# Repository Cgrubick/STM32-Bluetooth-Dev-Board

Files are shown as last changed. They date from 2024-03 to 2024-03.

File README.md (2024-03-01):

# STM32-Bluetooth-Dev-Board
STM32 based PCB design
By Clayton Grubick

Overview

This repository contains the design files, firmware, and documentation for a custom-designed PCB featuring an STM32 microcontroller with Bluetooth capabilities. The project is aimed at demonstrating advanced PCB design techniques, including RF circuitry for Bluetooth communication, making it suitable for a wide range of wireless applications.

Features:

  -STM32WB55CEU6 : Utilizes a high-performance STM32 MCU, offering ample processing power for complex applications

  -USB-C Connectivity: Utlizied USB-C with USB2.0 for connecting to the board and communication and power supply. Paired with the USB ESD protection IC

  -LDO Regulator: 5V to 3.3V supply

  -SWD Intereface: SWD connection for programming and debugging

  -RF Circuit: Impedence matching network and a LPF directed into a coaxial connection

  -Bootloader Button: Debouncing circuit and bootloader switch for firmware

  -UART Header Connection

This was my first higher level PCB design and also my first try at designing RF circuits, while the RF portion in this board is pretty trivial it was still a great exercise.

The low pass filter footprint is custom and the 3D model is also included under the 3D models folder, more info and data sheets are also included.

Schematic


PCB



3D view



TODO:

  -Manafuacture PCB
  
  -Write and load firmware onto board
  
  -Perform some simple embedded project with the board such as communication over bluetooth and sending and recieving data from an external computer

Credit/Inspo: Phils Lab

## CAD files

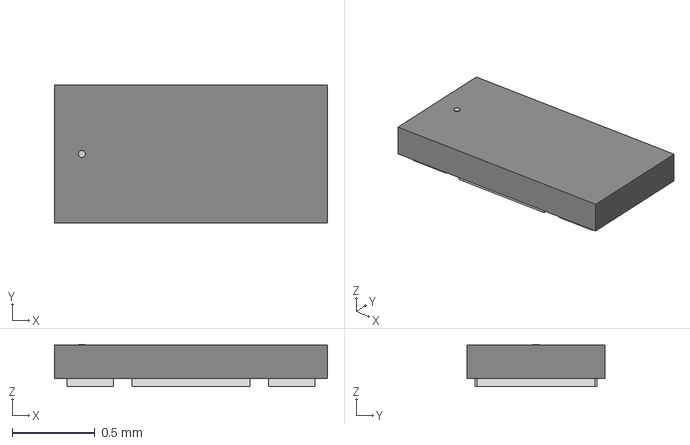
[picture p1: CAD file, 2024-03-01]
BluePillCopyCat/3D Models/DLF-4_1P6X0P8.step
1.65 x 0.838 x 0.257 mm

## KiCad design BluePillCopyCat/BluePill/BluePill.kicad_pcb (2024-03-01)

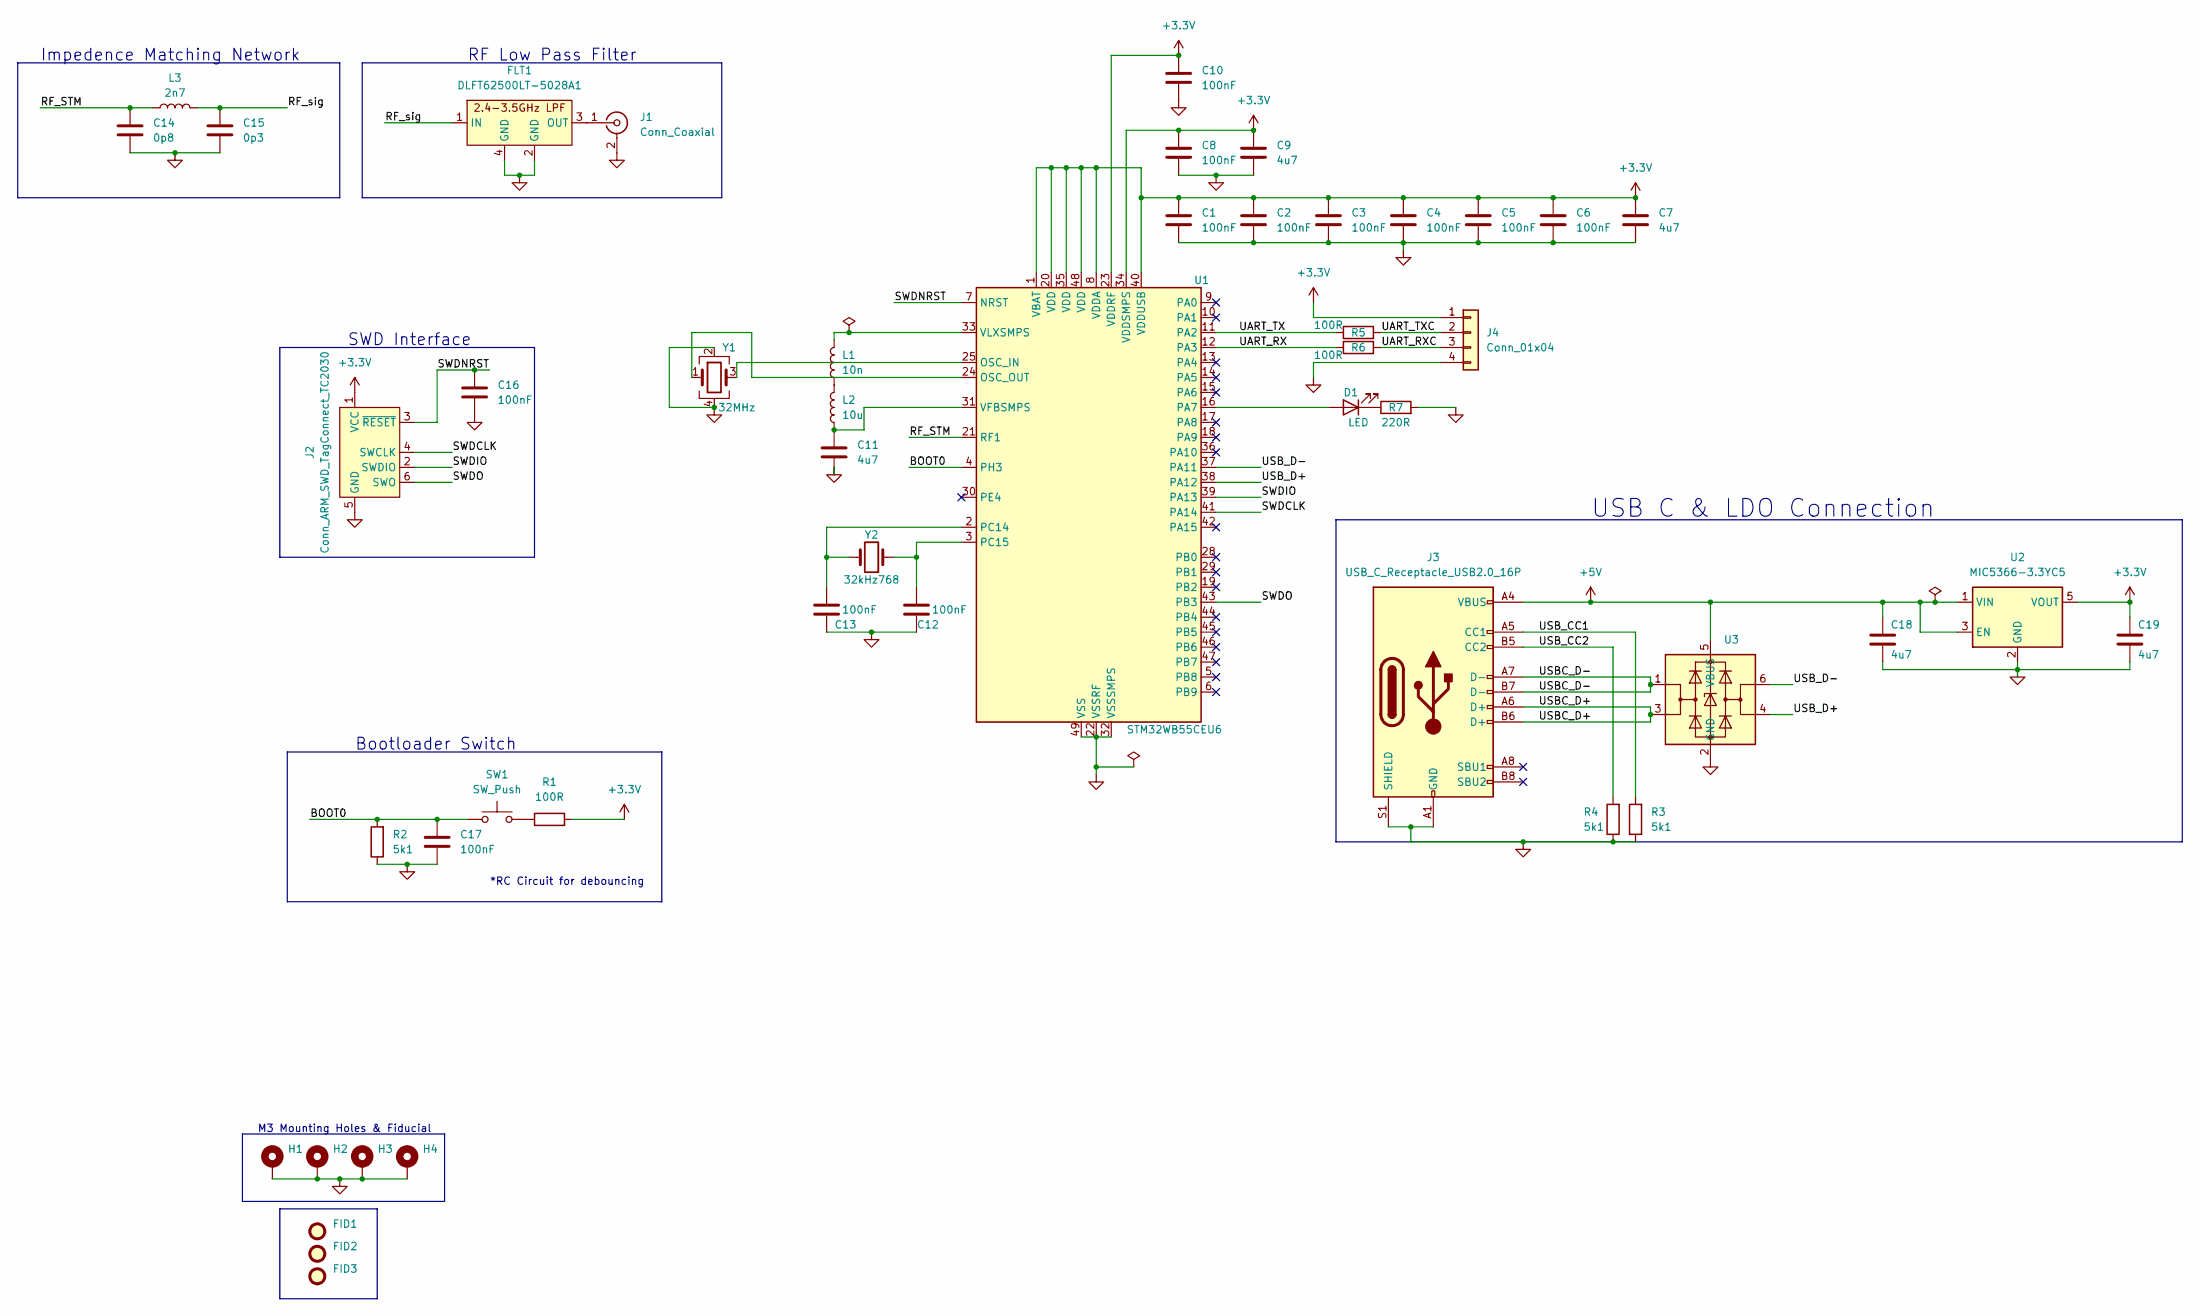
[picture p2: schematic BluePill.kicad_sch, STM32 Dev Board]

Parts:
C1, C2, C3, C4, C5, C6, C8, C10, C12, C13, C16, C17: 100nF; C_0402_1005Metric
C7, C9, C11, C18, C19: 4u7; C_0603_1608Metric
C14: 0p8; C_0402_1005Metric
C15: 0p3; C_0402_1005Metric
D1: LED; LED_0402_1005Metric
FID1, FID2, FID3: Fiducial; Fiducial_1mm_Mask2mm
FLT1: DLFT62500LT-5028A1
H1, H2, H3, H4: MountingHole_Pad; MountingHole_2.2mm_M2_Pad_Via
J1: Conn_Coaxial; U.FL_Hirose_U.FL-R-SMT-1_Vertical
J2: Conn_ARM_SWD_TagConnect_TC2030; Tag-Connect_TC2030-IDC-FP_2x03_P1.27mm_Vertical
J3: USB_C_Receptacle_USB2.0_16P; USB_C_Receptacle_GCT_USB4105-xx-A_16P_TopMnt_Horizontal
J4: Conn_01x04; PinSocket_1x04_P2.54mm_Vertical
L1: 10n; L_0402_1005Metric
L2: 10u; L_0805_2012Metric
L3: 2n7; L_0402_1005Metric
R1, R5, R6: 100R; R_0402_1005Metric
R2, R3, R4: 5k1; R_0402_1005Metric
R7: 220R; R_0402_1005Metric
SW1: SW_Push; SW_SPST_CK_RS282G05A3
U1: STM32WB55CEU6; QFN-48-1EP_7x7mm_P0.5mm_EP5.6x5.6mm
U2: MIC5366-3.3YC5; SOT-23-5
U3: SOT-23-6
Y1: 32MHz; Crystal_SMD_2016-4Pin_2.0x1.6mm
Y2: 32kHz768; Crystal_SMD_2012-2Pin_2.0x1.2mm

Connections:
+3.3V: C1.1, C2.1, C3.1, C4.1, C5.1, C6.1, C7.1, C8.1, C9.1, C10.1, C19.1, J2.1 (VCC), J4.1, R1.2, U1.1 (VBAT), U1.8 (VDDA), U1.20 (VDD), U1.23 (VDDRF), U1.34 (VDDSMPS), U1.35 (VDD), U1.40 (VDDUSB), U1.48 (VDD), U2.5 (VOUT)
+5V: C18.1, J3.A4 (VBUS), J3.A9 (VBUS), J3.B4 (VBUS), J3.B9 (VBUS), U2.1 (VIN), U2.3 (EN), U3.5 (VBUS)
/BOOT0: C17.1, R2.2, SW1.1, U1.4 (PH3)
/RF_STM: C14.1, L3.1, U1.21 (RF1)
/RF_sig: C15.1, FLT1.1 (IN), L3.2
/SWDCLK: J2.4 (SWCLK), U1.41 (PA14)
/SWDIO: J2.2 (SWDIO), U1.39 (PA13)
/SWDNRST: C16.1, J2.3 (~RESET), U1.7 (NRST)
/SWDO: J2.6 (SWO), U1.43 (PB3)
/UART_RX: R6.1, U1.12 (PA3)
/UART_RXC: J4.3, R6.2
/UART_TX: R5.1, U1.11 (PA2)
/UART_TXC: J4.2, R5.2
/USBC_D+: J3.A6 (D+), J3.B6 (D+), U3.3
/USBC_D-: J3.A7 (D-), J3.B7 (D-), U3.1
/USB_CC1: J3.A5 (CC1), R3.2
/USB_CC2: J3.B5 (CC2), R4.2
/USB_D+: U1.38 (PA12), U3.4
/USB_D-: U1.37 (PA11), U3.6
GND: C1.2, C2.2, C3.2, C4.2, C5.2, C6.2, C7.2, C8.2, C9.2, C10.2, C11.2, C12.1, C13.1, C14.2, C15.2, C16.2, C17.2, C18.2, C19.2, FLT1.2 (GND), FLT1.4 (GND), H1.1, H2.1, H3.1, H4.1, J1.2 (Ext), J2.5 (GND), J3.A1 (GND), J3.A12 (GND), J3.B1 (GND), J3.B12 (GND), J3.S1 (SHIELD), J4.4, R2.1, R3.1, R4.1, R7.2, U1.22 (VSSRF), U1.32 (VSSSMPS), U1.49 (VSS), U2.2 (GND), U3.2 (GND), Y1.2, Y1.4
unnamed: D1.2 (A), U1.16 (PA7)
unnamed: D1.1 (K), R7.1
unnamed: FLT1.3 (OUT), J1.1 (In)
unnamed: L1.1, L2.2
unnamed: R1.1, SW1.2
unnamed: U1.25 (OSC_IN), Y1.3
unnamed: U1.24 (OSC_OUT), Y1.1
unnamed: C13.2, U1.2 (PC14), Y2.2
unnamed: C12.2, U1.3 (PC15), Y2.1
unnamed: C11.1, L2.1, U1.31 (VFBSMPS)
unnamed: L1.2, U1.33 (VLXSMPS)

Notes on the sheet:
SWD Interface
M3 Mounting Holes & Fiducial
*RC Circuit for debouncing
RF Low Pass Filter
USB C & LDO Connection
Bootloader Switch
Impedence Matching Network

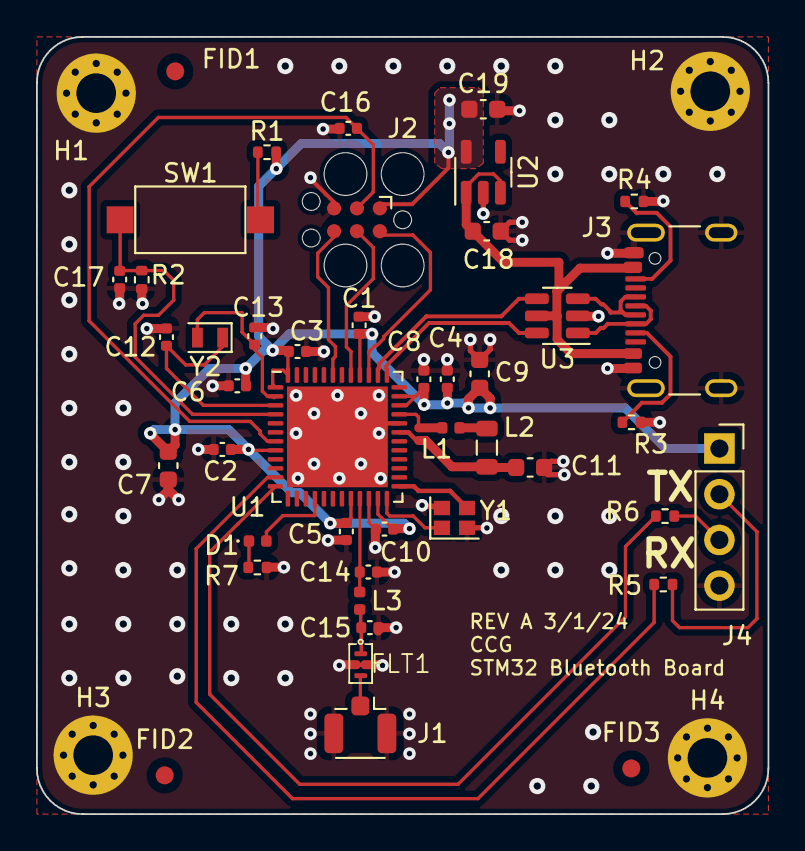
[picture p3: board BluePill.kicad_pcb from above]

Board: 4 copper layers, 40.6 x 43.2 mm, 48 parts (0 on the bottom side), 31 nets.
